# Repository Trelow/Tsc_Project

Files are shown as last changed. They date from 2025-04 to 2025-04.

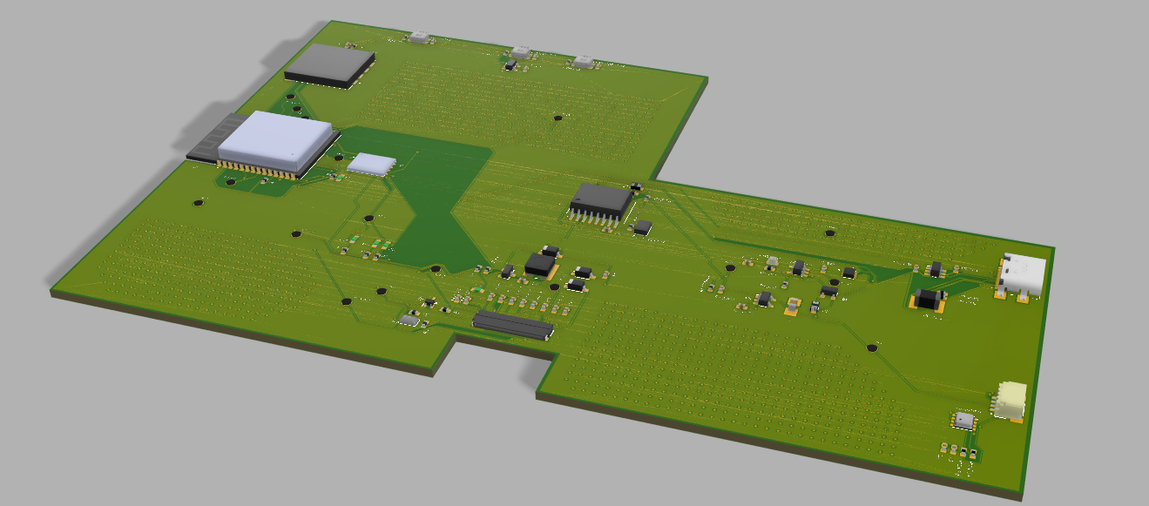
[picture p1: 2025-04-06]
Images/4.png

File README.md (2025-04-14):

# OpenBook Reader

```mermaid
graph TD
    
    USB["USB-C Connector(ESD Protection)"] -->|5V| CHG["Battery Charger (MCP73831)"]
    CHG -->|Charging| BATT["Li-Po Battery (2500mAh)"]
    BATT --> LDO["3.3V LDO Regulator (XC6220)"]

    LDO -->|3.3V| ESP["ESP32-C6-WROOM-1(MCU)"]

    ESP -- I2C --> RTC["Real Time Clock(DS3231)"]
    ESP -- I2C --> BME["Environmental Sensor(BME688)"]
    ESP -- I2C --> FUEL["Battery Fuel Gauge(MAX17048)"]
    ESP -- I2C --> QWIIC["Qwiic / Stemma QT"]

    ESP -- SPI --> FLASH["External NOR Flash(W25Q512)"]
    ESP -- SPI --> SD["MicroSD Card Slot"]
    ESP -- SPI --> EPD_HEADER["E-Paper Display Header"]

    EPD_HEADER --> EPD_DRIVER["EPD Driver Circuit"]
    EPD_DRIVER --> EPD_POW["EPD HV Power"]
    LDO --> EPD_HEADER

    ESP -- GPIO --> BUTTONS["3x Buttons:BOOT, CHANGE, RESET"]

    USB -- USB D+/D- --> ESP
```

## Tabel Componente Principale (BOM)

| Parts | Device | Check Prices | Datasheet |
|---|---|---|---|
|R1, R2 .. | ESP32_WROVER_EAGLE-LTSPICE_RR0402 |https://componentsearchengine.com/part-view/R0402%201%25%20100%20K%20 | https://componentsearchengine.com/part-view/R0402%201%25%20100%20K%20 |
| L1 | 744043680IND_4828-WE-TPC_WRE |  https://eu.mouser.com/ProductDetail/Wurth-Elektronik/744043680?qs=PGXP4M47uW6VkZq%252BkzjrHA%3D%3D | https://eu.mouser.com/ProductDetail/Wurth-Elektronik/744043680?qs=PGXP4M47uW6VkZq%252BkzjrHA%3D%3D |
| IC1 | BD5229G-TR |https://componentsearchengine.com/part-view/BD5229G-TR/ROHM%20Semiconductor | https://componentsearchengine.com/part-view/BD5229G-TR/ROHM%20Semiconductor |
| SENSOR2 | ESP32_WROVER_BME680_BME680 | https://www.snapeda.com/parts/BME680/Bosch/view-part/?welcome=home | https://www.snapeda.com/parts/BME680/Bosch/view-part/?welcome=home |
| SJ1 | SJ | https://grabcad.com/library/solder-jumpers-1 | https://grabcad.com/library/solder-jumpers-1 |
| BOOT_BUTTON, CHANGE_BUTTON, RESET_BUTTON | BUTTON_CUSYOMV1 | https://industry.panasonic.com/global/en/products/control/switch/light-touch/number/evqpuj02k | https://industry.panasonic.com/global/en/products/control/switch/light-touch/number/evqpuj02k |
| C1, C2 .. | CPH3225A | https://www.snapeda.com/parts/CPH3225A/Seiko+Instruments/view-part/?ref=eda | - |
| U3 | DS3231SN# | https://www.snapeda.com/parts/DS3231SN%23/Analog+Devices/view-part/?ref=eda | [Datasheet](https://www.analog.com/media/en/technical-documentation/data-sheets/ds3231.pdf) |
| U2 | ESP32-C6-WROOM-1-N8 | https://www.snapeda.com/parts/ESP32-C6-WROOM-1-N8/Espressif+Systems/view-part/?ref=eda | - |
| PFMF.050.1 | ESP32C6_VARISTORCN1812| https://www.mouser.co.uk/ProductDetail/EPCOS-TDK/B72520T0350K062?qs=dEfas%2FXlABIszF52uu7vrg%3D%3D | https://www.mouser.co.uk/ProductDetail/EPCOS-TDK/B72520T0350K062?qs=dEfas%2FXlABIszF52uu7vrg%3D%3D |
| D2 | ESP32_WROVER_AVX---SD0805S020S1R0 | https://eu.mouser.com/ProductDetail/KYOCERA-AVX/SD0805S020S1R0?qs=jCA%252BPfw4LHbpkAoSnwrdjw%3D%3D | http://datasheets.avx.com/schottky.pdf |
| MCP73831 | ESP32_WROVER_SPARKFUN-IC-POWER_MCP73831 |  https://eu.mouser.com/ProductDetail/Microchip-Technology/MCP73831T-2ACI-OT?qs=yUQqVecv4qvbBQBGbHx0Mw%3D%3Dcf |
| J1 | FH34SRJ-24S-0.5SH_99_ | https://componentsearchengine.com/part-view/XC6220A331MR-G/Torex | https://componentsearchengine.com/part-view/XC6220A331MR-G/Torex |
| U4 | MAX17048G+T10 | https://www.snapeda.com/parts/MAX17048G+T10/Analog+Devices/view-part/?ref=eda | - |
| D3, D4, D5 | MBR0530 | https://www.snapeda.com/parts/MBR0530/Onsemi/view-part/?ref=eda | - |
| D6, D8, D9, D10, D11, D12 | PGB1010603MR | https://www.snapeda.com/parts/PGB1010603MR/Littelfuse/view-part/?ref=eda | - |
| J3 | QWIIC_CONNECTORJS-1MM | - | - |
| J2 | SAMACSYS_PARTS_USB4110-GF-A |https://www.mouser.com/ProductDetail/GCT/USB4110-GF-A | https://gct.co/files/drawings/usb4110.pdf |
| D7 | ESP32_WROVER_AVX---SD0805S020S1R0 | - | [Datasheet](http://datasheets.avx.com/schottky.pdf) |
| BOOT_BUTTON | EVQPUJ02K | https://www.mouser.com/ProductDetail/Panasonic/EVQPUJ02K | [Datasheet](https://na.industrial.panasonic.com/file-download/21900) |
| Q3 | SI1308EDL-T1-GE3 | https://componentsearchengine.com/part-view/SI1308EDL-T1-GE3/Vishay | https://componentsearchengine.com/part-view/SI1308EDL-T1-GE3/Vishay |
| TP1, TP2, ..., TP17 | TPTP20R | - | - |
| D1 | USBLC6-2SC6Y |  https://www.snapeda.com/parts/USBLC6-2SC6Y/STMicroelectronics/view-part/?ref=eda | https://www.snapeda.com/parts/USBLC6-2SC6Y/STMicroelectronics/view-part/?ref=eda |
| U1 | W25Q512JVEIQ | https://www.snapeda.com/parts/W25Q512JVEIQ/Winbond+Electronics/view-part/?ref=eda | - |
| IC4 | XC6220A331MR-G | https://www.mouser.com/ProductDetail/Torex-Semiconductor/XC6220A331MR-G) | https://www.torexsemi.com/file/xc6220/XC6220.pdf |

## Descriere Detaliată a Funcționalității Hardware

### 1. Microcontroller – ESP32-C6
Dispozitivul folosește microcontroller-ul ESP32-C6-WROOM-1-N8, echipat cu un nucleu RISC-V pe 32 de biți, cu o frecvență maximă de 160 MHz.

- **Memorie:** 512 KB SRAM internă și flash extern de 8 MB (W25Q512JVEIQ).
- **Conectivitate:** Wi-Fi 6, Bluetooth 5 LE, interfață USB 2.0.
- **Periferice:** Suport SPI, I²C, UART și GPIO multipli.
- **Eficiență energetică:** Moduri sleep și deep sleep optimizate pentru utilizarea eficientă a bateriei.

### 2. Afișaj E-Paper
Afișaj E-Ink de 7.5” cu rezoluție de 800×480 pixeli

- **Interfață:** SPI 4-wire cu pini adiționali (CS, DC, RST, BUSY).
- **Consum:** Foarte redus în stare statică; crește doar temporar în timpul actualizării imaginii (aproximativ 15-25 mA).
- **Beneficii:** Imaginea este păstrată fără consum electric, ideal pentru dispozitive portabile tip e-reader.

### 3. Senzor Mediu – BME680
Senzor multifuncțional care măsoară temperatura, umiditatea, presiunea atmosferică și calitatea aerului (VOC/eCO₂).

- **Interfață:** I²C cu viteză de până la 400 kHz.
- **Consum:** Aproximativ 2.1µA în mod standby și câțiva mA la citiri active.
- **Avantaj principal:** Integrează multiple funcții de mediu într-un singur cip compact și eficient.

### 4. Management Energetic & Baterie
Sistemul energetic este bazat pe o baterie Li-Po de 3.7V și capacitate de 2500mAh, pentru autonomie extinsă.

- **Încărcare:** MCP73831, încărcare rapidă prin USB-C (maxim 1A).
- **Monitorizare:** MAX17048 comunică starea bateriei prin interfața I²C.
- **Regulator:** XC6220A331MR-G oferă tensiunea stabilă de 3.3V pentru componentele critice.

### 5. Interfață Utilizator – Butoane
Sunt incluse trei butoane tactile dedicate navigării, selecției și întoarcerii paginilor, fiecare conectat la GPIO cu debouncing hardware (rezistor și condensator) sau software.

### 6. Conector USB-C
- **Funcții principale:** Încărcarea acumulatorului, transferul de date (USB 2.0) și actualizarea firmware-ului. Utilizare de diode ESD (ex: USBLC6-2SC6Y) și rezistențe specifice pentru conformitate cu USB-C.

### 8. Slot MicroSD (112A-TAAR-R03)
- **Utilizare:** Stocare log-uri, cărți electronice și actualizări de firmware.
- **Interfață:** Compatibil cu SD (mod 1-bit sau 4-bit) sau SPI, configurabil în firmware.

### 8. Conector Qwiic (I²C)
Conector standardizat cu patru pini (VCC, GND, SDA, SCL) pentru extinderea rapidă a funcționalităților prin senzori sau module suplimentare.

### 9. RTC DS3231
- **Precizie:** Foarte ridicată.
- **Interfață:** Comunicare I²C integrată cu ceilalți senzori.

### 10. Memorie Flash Externă – W25Q512JVEIQ
- **Interfață:** Quad SPI pentru acces rapid la date.
- **Utilizare:** Stocarea aplicațiilor, imaginilor și fișierelor mari, inclusiv cărți electronice.

## Estimare Consum Energetic
- **Activ (Wi-Fi + refresh ecran):** Aproximativ 150 mA
- **Citire (ecran static):** Aproximativ 10 mA
- **Deep Sleep:** Sub 50 µA
- **Autonomie:** Aproximativ o săptămână, considerând un consum mediu de 10 mA (2500mAh ~250 ore utilizare).

## Estimare Consum de Energie
- **Activ (Wi-Fi + Refresh ecran)**: ~150mA  
- **Citire (ecran static)**: ~10mA  
- **Deep Sleep**: <50µA  
- **Autonomie estimată**: ~1 săptămână (la o utilizare medie de 10mA, o baterie de 2500mAh durează ~250 ore).

---

## Atribuirea Pinilor pe ESP32-C6

| Pin  | Funcție | Componentă | Descriere Utilizare |
|-----:|:---|:---|:---|
| GPIO0  | BOOT_BUTTON | Buton | Boot mode la pornire |
| GPIO1  | RESET_BUTTON | Buton | Reset manual |
| GPIO2  | CHANGE_BUTTON  | Buton | Navigare meniu |
| GPIO3  | EPD_CS | Display E-Paper | Chip Select (SPI) |
| GPIO4  | EPD_DC | Display E-Paper | Data/Command control |
| GPIO5  | EPD_RST | Display E-Paper | Reset ecran |
| GPIO6  | EPD_BUSY | Display E-Paper | Semnal stare refresh |
| GPIO7  | SPI_MOSI | Display, Flash, SD  | Master Out Slave In (SPI) |
| GPIO8  | SPI_MISO | Display, Flash, SD  | Master In Slave Out (SPI) |
| GPIO9  | SPI_SCK | Display, Flash, SD  | Clock SPI |
| GPIO10 | FLASH_CS | W25Q512JVEIQ | Chip Select pentru Flash |
| GPIO11 | SD_CS | Micro SD (opțional) | Chip Select card SD |
| GPIO12 | I2C_SDA | BME680, MAX17048, DS3231 | Linie date I2C |
| GPIO13 | I2C_SCL | BME680, MAX17048, DS3231 | Linie clock I2C |
| GPIO14 | CHG_LED | LED încărcare | Status încărcare |
| GPIO15 | UART_TX | Debugging | TX serial |
| GPIO16 | UART_RX | Debugging | RX serial |
| GPIO17 | USB_D+ | USB-C | Linie date USB + |
| GPIO18 | USB_D- | USB-C | Linie date USB – |

---

## Concluzii
Prin acest README, aveți la dispoziție elementele cheie ale construcției hardware pentru e-reader-ul **OpenBook**: modulul ESP32-C6, ecranul e-paper, senzorii, alimentarea și circuitele de încărcare. Fișierul CSV atașat oferă o listă detaliată a componentelor (BOM).

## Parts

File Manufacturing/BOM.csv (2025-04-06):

Qty | Value | Device | Package | Parts | Description | ARROW_PART_NUMBER | ARROW_PRICE-STOCK | AVAILABILITY | CENTROID_NOT_SPECIFIED | CHECK_PRICES | COPYRIGHT | DATASHEET | DESCRIPTION | DIGIKEY_DESCRIPTION | DIGIKEY_PART_NUMBER | HEIGHT | LEAD_FREE | MANUFACTURER_NAME | MANUFACTURER_PART_NUMBER | MF | MFR_NAME | MOUSER_PART_NUMBER | MOUSER_PRICE-STOCK | MOUSER_TESTING_PART_NUMBER | MOUSER_TESTING_PRICE-STOCK | MP | MPN | PACKAGE | POPULARITY | PREFIX | PRICE | PROD_ID | PURCHASE-URL | P_CHANNEL | ROHS | SNAPEDA_LINK | SPICEMODEL | SPICEPREFIX | TEMPERATURE_RANGE_HIGH | TEMPERATURE_RANGE_LOW | TP_SIGNAL_NAME | TYPE | VALUE | VALUE_TXT
1 |  | ADAFRUIT_LEDCHIP-LED0603 | ADAFRUIT_CHIP-LED0603 | CHG_LED | LED
1 |  | SJ | SJ | SJ1 | SMD solder JUMPER |  |  |  |  |  |  |  |  |  |  |  |  |  |  |  |  |  |  |  |  |  |  |  | 3
1 | 0.1uF/50V | ESP32_WROVER_EAGLE-LTSPICE_CC0402 | ESP32_WROVER_EAGLE-LTSPICE_C0402 | EPD_C5 | CAPACITOR, European symbol |  |  |  |  |  |  |  |  |  |  |  |  |  |  |  |  |  |  |  |  |  |  |  |  |  |  |  |  |  |  |  | NONE | C
1 | 0.47 | ESP32_WROVER_EAGLE-LTSPICE_RR0402 | ESP32_WROVER_EAGLE-LTSPICE_R0402 | R3 | RESISTOR, European symbol |  |  |  |  |  |  |  |  |  |  |  |  |  |  |  |  |  |  |  |  |  |  |  |  |  |  |  |  |  |  |  | NONE | R
1 | 100K | ESP32_WROVER_EAGLE-LTSPICE_RR0402 | ESP32_WROVER_EAGLE-LTSPICE_R0402 | R1_PWRUSB | RESISTOR, European symbol |  |  |  |  |  |  |  |  |  |  |  |  |  |  |  |  |  |  |  |  |  |  |  |  |  |  |  |  |  |  |  | NONE | R
8 | 100nF | ESP32_WROVER_EAGLE-LTSPICE_CC0402 | ESP32_WROVER_EAGLE-LTSPICE_C0402 | C1, C2, C4_USB, C6, C8, C9, C10, C_DELAY | CAPACITOR, European symbol |  |  |  |  |  |  |  |  |  |  |  |  |  |  |  |  |  |  |  |  |  |  |  |  |  |  |  |  |  |  |  | NONE | C
1 | 100uF | RCL_CPOL-EUCT3528 | RCL_CT3528 | C3 | POLARIZED CAPACITOR, European symbol |  |  |  |  |  |  |  |  |  |  |  |  |  |  |  |  |  |  |  |  |  |  |  | 0 |  |  |  |  |  |  |  |  | C |  |  |  | TANT
16 | 10K | ESP32_WROVER_EAGLE-LTSPICE_RR0402 | ESP32_WROVER_EAGLE-LTSPICE_R0402 | R1, R1_PINH, R1_PINH1, R2_PINH, R2_PINH1, R4, R5, R6, R7, R8, R9, R10, R_BOOT, R_CHANGE, R_CL1, R_RESET | RESISTOR, European symbol |  |  |  |  |  |  |  |  |  |  |  |  |  |  |  |  |  |  |  |  |  |  |  |  |  |  |  |  |  |  |  | NONE | R
1 | 10uF | ESP32_WROVER_EAGLE-LTSPICE_CC0402 | ESP32_WROVER_EAGLE-LTSPICE_C0402 | C7 | CAPACITOR, European symbol |  |  |  |  |  |  |  |  |  |  |  |  |  |  |  |  |  |  |  |  |  |  |  |  |  |  |  |  |  |  |  | NONE | C
1 | 112A-TAAR-R03_ATTEND | 112A-TAAR-R03_ATTEND | 112ATAARR03ATTEND | J4 | Micro SD Card Socket, Push-Push Type, Top Mount, SMT, H=1.83mm, 10u |  |  |  |  |  |  |  | Micro SD Card Socket | Push-Push Type | Top Mount | SMT | H=1.83mm | 10u |  |  | 1.9mm |  | ATTEND | 112A-TAAR-R03 ATTEND
1 | 15 | ESP32_WROVER_EAGLE-LTSPICE_RR0402 | ESP32_WROVER_EAGLE-LTSPICE_R0402 | R1_CAPACITOR | RESISTOR, European symbol |  |  |  |  |  |  |  |  |  |  |  |  |  |  |  |  |  |  |  |  |  |  |  |  |  |  |  |  |  |  |  | NONE | R
1 | 1uF | ESP32_WROVER_EAGLE-LTSPICE_CC0402 | ESP32_WROVER_EAGLE-LTSPICE_C0402 | C5 | CAPACITOR, European symbol |  |  |  |  |  |  |  |  |  |  |  |  |  |  |  |  |  |  |  |  |  |  |  |  |  |  |  |  |  |  |  | NONE | C
9 | 1uF/50V | ESP32_WROVER_EAGLE-LTSPICE_CC0402 | ESP32_WROVER_EAGLE-LTSPICE_C0402 | EPD_C1, EPD_C2, EPD_C6, EPD_C7, EPD_C8, EPD_C9, EPD_C10, EPD_C11, EPD_C12 | CAPACITOR, European symbol |  |  |  |  |  |  |  |  |  |  |  |  |  |  |  |  |  |  |  |  |  |  |  |  |  |  |  |  |  |  |  | NONE | C
1 | 2.2 | ESP32_WROVER_EAGLE-LTSPICE_RR0402 | ESP32_WROVER_EAGLE-LTSPICE_R0402 | R2 | RESISTOR, European symbol |  |  |  |  |  |  |  |  |  |  |  |  |  |  |  |  |  |  |  |  |  |  |  |  |  |  |  |  |  |  |  | NONE | R
1 | 200 | ESP32_WROVER_EAGLE-LTSPICE_RR0402 | ESP32_WROVER_EAGLE-LTSPICE_R0402 | R1_BAT | RESISTOR, European symbol |  |  |  |  |  |  |  |  |  |  |  |  |  |  |  |  |  |  |  |  |  |  |  |  |  |  |  |  |  |  |  | NONE | R
2 | 20V/4.2A/52m?/1.4W | ESP32_WROVER_SPARKFUN-DISCRETESEMI_MOSFET_PCH-DMG2305UX-7 | ESP32_WROVER_SPARKFUN-DISCRETESEMI_SOT23-3 | Q1, Q2 | P-channel MOSFETs |  |  |  |  |  |  |  |  |  |  |  |  |  |  |  |  |  |  |  |  |  |  |  |  |  |  | TRAN-14388 |  | DMG2305UX-7 |  |  |  |  |  |  |  |  | 20V/4.2A/52m?/1.4W
1 | 2K | ESP32_WROVER_EAGLE-LTSPICE_RR0402 | ESP32_WROVER_EAGLE-LTSPICE_R0402 | R2_BAT | RESISTOR, European symbol |  |  |  |  |  |  |  |  |  |  |  |  |  |  |  |  |  |  |  |  |  |  |  |  |  |  |  |  |  |  |  | NONE | R
5 | 4.7uF | ESP32_WROVER_EAGLE-LTSPICE_CC0402 | ESP32_WROVER_EAGLE-LTSPICE_C0402 | C1_BAT, C1_BAT1, C1_BAT2, C2_BAT, C5_USB | CAPACITOR, European symbol |  |  |  |  |  |  |  |  |  |  |  |  |  |  |  |  |  |  |  |  |  |  |  |  |  |  |  |  |  |  |  | NONE | C
1 | 4.7uF/25V | ESP32_WROVER_EAGLE-LTSPICE_CC0402 | ESP32_WROVER_EAGLE-LTSPICE_C0402 | C4 | CAPACITOR, European symbol |  |  |  |  |  |  |  |  |  |  |  |  |  |  |  |  |  |  |  |  |  |  |  |  |  |  |  |  |  |  |  | NONE | C
2 | 5k1 | ESP32_WROVER_EAGLE-LTSPICE_RR0402 | ESP32_WROVER_EAGLE-LTSPICE_R0402 | R2-USB, R2-USB1 | RESISTOR, European symbol |  |  |  |  |  |  |  |  |  |  |  |  |  |  |  |  |  |  |  |  |  |  |  |  |  |  |  |  |  |  |  | NONE | R
1 | 68uH | 744043680IND_4828-WE-TPC_WRE | IND_4828-WE-TPC_WRE | L1 |  |  |  |  |  |  | Copyright (C) 2024 Ultra Librarian. All rights reserved. |  |  |  |  |  |  |  | 744043680 |  | Wurth Electronics
1 | BD5229G-TR | BD5229G-TR | SOT95P280X125-5N | IC1 | Voltage Detector with Adjustable Delay Time: CMOS processes are utilized to develop high precision, low current consumption CMOS reset ICs that allow arbitrary setting of the delay time. The extensive lineup includes both Nch Open Drain and CMOS output types in a wide range of detection voltages (from 2.3V to 6.0V, in 0.1V steps), enabling selection of the ideal solution based on customer requirements. In addition, the entire series is of course both lead-free and RoHS-compliant. |  |  |  |  |  |  |  | Voltage Detector with Adjustable Delay Time: CMOS processes are utilized to develop high precision | low current consumption CMOS reset ICs that allow arbitrary setting of the delay time. The extensive lineup includes both Nch Open Drain and CMOS output types in a wide range of detection voltages (from 2.3V to 6.0V | in 0.1V steps) | enabling selection of the ideal solution based on customer requirements. In addition | the entire series is of course both lead-free and RoHS-compliant. |  |  | 1.25mm |  | ROHM Semiconductor | BD5229G-TR |  |  | 755-BD5229G-TR | https://www.mouser.co.uk/ProductDetail/ROHM-Semiconductor/BD5229G-TR?qs=4kLU8WoGk0vvnhrrYwdszw%3D%3D
1 | BME688 | ESP32_WROVER_BME680_BME680 | ESP32_WROVER_BME680_PSON80P300X300X100-8N | SENSOR2 | Integrated Environmental Unit |  |  | Unavailable |  |  |  |  | Integrated Environmental Unit |  |  |  |  |  |  | Bosch Sensortec |  |  |  |  |  | BME680 |  | LGA-8 Bosch Tools |  |  | None
3 | BUTTON_CUSYOMV1 | BUTTON_CUSYOMV1 | MYBUTTON | BOOT_BUTTON, CHANGE_BUTTON, RESET_BUTTON
1 | CPH3225A | CPH3225A | CAPCP3225X100N | C10_SUPERCAP | Cap 0.011F 3.3V 1210 Flat Check availability |  |  | Not in stock |  | https://www.snapeda.com/parts/CPH3225A/Seiko+Instruments/view-part/?ref=eda |  |  | 11 mF (EDLC) Supercapacitor 3.3 V 1210 (3225 Metric) - - |  |  |  |  |  |  | Seiko Instruments |  |  |  |  |  | CPH3225A |  | 1210 Seiko |  |  | None |  | https://www.snapeda.com/api/url_track_click_mouser/?unipart_id=562593&manufacturer=Seiko Instruments&part_name=CPH3225A&search_term=None |  |  | https://www.snapeda.com/parts/CPH3225A/Seiko+Instruments/view-part/?ref=snap
1 | DS3231SN# | DS3231SN# | SOIC127P1032X265-16N | U3 | Real Time Clock Serial 16-Pin SOIC W T/R Check availability |  |  | In Stock |  | https://www.snapeda.com/parts/DS3231SN%23/Analog+Devices/view-part/?ref=eda |  |  | Extremely Accurate I?C-Integrated RTC/TCXO/Crystal |  |  |  |  |  |  | Analog Devices |  |  |  |  |  | DS3231SN# |  | SOIC-16 Maxim |  |  | None |  | https://www.snapeda.com/api/url_track_click_mouser/?unipart_id=99048&manufacturer=Analog Devices&part_name=DS3231SN#&search_term=None |  |  | https://www.snapeda.com/parts/DS3231SN%23/Analog+Devices/view-part/?ref=snap
1 | ESP32-C6-WROOM-1-N8 | ESP32-C6-WROOM-1-N8 | XCVR_ESP32-C6-WROOM-1-N8 | U2 | Check availability |  |  | In Stock |  | https://www.snapeda.com/parts/ESP32-C6-WROOM-1-N8/Espressif+Systems/view-part/?ref=eda |  |  | Multiprotocol Modules ESP32-C6 module | Wi-Fi 6 in 2.4 GHz band | Bluetooth 5 | Zigbee 3.0 and Thread. ESP34-WROOM Compatible - ENGINEERING SAMPLE |  |  |  |  |  |  | Espressif Systems |  |  |  |  |  | ESP32-C6-WROOM-1-N8 |  | None |  |  | None |  |  |  |  | https://www.snapeda.com/parts/ESP32-C6-WROOM-1-N8/Espressif+Systems/view-part/?ref=snap
1 | ESP32C6_VARISTORCN1812 | ESP32C6_VARISTORCN1812 | ESP32C6_VARISTOR_CT/CN1812 | PFMF.050.1 | VARISTOR |  |  |  |  |  |  |  |  |  |  |  |  |  |  |  |  |  |  |  |  |  |  |  | 0
1 | ESP32_WROVER_AVX---SD0805S020S1R0_AVX_SD0805S020S1R0_0_0AVX_SD0805S020S1R0_0_0 | ESP32_WROVER_AVX---SD0805S020S1R0_AVX_SD0805S020S1R0_0_0AVX_SD0805S020S1R0_0_0 | ESP32_WROVER_AVX---SD0805S020S1R0_AVX_SD0805S020S1R0_0 | D2 | Schottky Barrier Rectifier Diode |  |  |  | No |  |  | http://datasheets.avx.com/schottky.pdf |  | DIODE SCHOTTKY 20V 1A 0805 | 478-7800-1-ND |  | yes |  |  | AVX |  | 581-SD0805S020S1R0 |  |  |  |  |  | 0805 (2012 metric) |  | D |  |  |  |  | yes |  |  |  | +125°C | -55°C |  |  |  | SD0805S020S1R0
1 | ESP32_WROVER_SPARKFUN-IC-POWER_MCP73831 | ESP32_WROVER_SPARKFUN-IC-POWER_MCP73831 | ESP32_WROVER_SPARKFUN-IC-POWER_SOT23-5 | MCP73831 | MCP73831T Li-Ion, Li-Pol Controller |  |  |  |  |  |  |  |  |  |  |  |  |  |  |  |  |  |  |  |  |  |  |  |  |  |  | IC-09995
1 | FH34SRJ-24S-0.5SH_99_ | FH34SRJ-24S-0.5SH_99_ | FH34SRJ24S05SH99 | J1 | (0.50mm) Surface Mount, Right Angle |  |  |  |  |  |  |  | 24 Position FFC | FPC Connector Contacts | (0.50mm) Surface Mount | Right Angle |  |  | 1.1mm |  | Hirose | FH34SRJ-24S-0.5SH(99) |  |  | 798-FH34SRJ24S05SH99 | https://www.mouser.co.uk/ProductDetail/Hirose-Connector/FH34SRJ-24S-0.5SH99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
1 | MAX17048G+T10 | MAX17048G+T10 | SON50P200X200X80-9N | U4 | Check availability |  |  | In Stock |  | https://www.snapeda.com/parts/MAX17048G+T10/Analog+Devices/view-part/?ref=eda |  |  | 3µA 1-Cell/2-Cell Fuel Gauge with ModelGauge |  |  |  |  |  |  | Analog Devices |  |  |  |  |  | MAX17048G+T10 |  | TDFN-8 Maxim |  |  | None |  | https://www.snapeda.com/api/url_track_click_mouser/?unipart_id=329239&manufacturer=Analog Devices&part_name=MAX17048G+T10&search_term=None |  |  | https://www.snapeda.com/parts/MAX17048G+T10/Analog+Devices/view-part/?ref=snap
3 | MBR0530 | MBR0530 | SOD3716X135N | D3, D4, D5 | ON SEMICONDUCTOR - MBR0530 - DIODE, SCHOTTKY, 0.5A, 30V, SOD-123 |  |  | In Stock |  | https://www.snapeda.com/parts/MBR0530/Onsemi/view-part/?ref=eda |  |  | Diode Schottky 30 V 500mA Surface Mount SOD-123 |  |  |  |  |  |  | ON Semiconductor |  |  |  |  |  | MBR0530 |  | SOD-123-2 ON Semiconductor |  |  | None |  | https://www.snapeda.com/api/url_track_click_mouser/?unipart_id=179458&manufacturer=ON Semiconductor&part_name=MBR0530&search_term=None |  |  | https://www.snapeda.com/parts/MBR0530/Onsemi/view-part/?ref=snap
6 | PGB1010603MR | PGB1010603MR | DIOC1608X36N | D6, D8, D9, D10, D11, D12 | Check availability |  |  | In Stock |  | https://www.snapeda.com/parts/PGB1010603MR/Littelfuse/view-part/?ref=eda |  |  | 150V (Typ) Clamp - Ipp Tvs Diode Surface Mount 0603 (1608 Metric) |  |  |  |  |  |  | Littelfuse Inc. |  |  |  |  |  | PGB1010603MR |  | 0603 Littelfuse Inc. |  |  | None |  | https://www.snapeda.com/api/url_track_click_mouser/?unipart_id=5659453&manufacturer=Littelfuse Inc.&part_name=PGB1010603MR&search_term=None |  |  | https://www.snapeda.com/parts/PGB1010603MR/Littelfuse/view-part/?ref=snap
1 | QWIIC_RIGHT_ANGLE | QWIIC_CONNECTORJS-1MM | JST04_1MM_RA | J3 | SparkFun I2C Standard Qwiic Connector |  |  |  |  |  |  |  |  |  |  |  |  |  |  |  |  |  |  |  |  |  |  |  |  |  |  | CONN-13694 |  |  |  |  |  |  |  |  |  |  | QWIIC_RIGHT_ANGLE
1 | SAMACSYS_PARTS_USB4110-GF-A | SAMACSYS_PARTS_USB4110-GF-A | SAMACSYS_PARTS_USB4110GFA | J2 | CONN USB 2.0 TYPE-C R/A SMT |  |  |  |  |  |  |  | CONN USB 2.0 TYPE-C R/A SMT |  |  | 3.26mm |  | GCT (GLOBAL CONNECTOR TECHNOLOGY) | USB4110-GF-A |  |  | 640-USB4110-GF-A | https://www.mouser.co.uk/ProductDetail/GCT/USB4110-GF-A?qs=KUoIvG%2F9IlYiZvIXQjyJeA%3D%3D
1 | SD0805S020S1R0 | ESP32_WROVER_AVX---SD0805S020S1R0_AVX_SD0805S020S1R0_0_0AVX_SD0805S020S1R0_0_0 | ESP32_WROVER_AVX---SD0805S020S1R0_AVX_SD0805S020S1R0_0 | D7 | Schottky Barrier Rectifier Diode |  |  |  | No |  |  | http://datasheets.avx.com/schottky.pdf |  | DIODE SCHOTTKY 20V 1A 0805 | 478-7800-1-ND |  | yes |  |  | AVX |  | 581-SD0805S020S1R0 |  |  |  |  |  | 0805 (2012 metric) |  | D |  |  |  |  | yes |  |  |  | +125°C | -55°C |  |  |  | SD0805S020S1R0
1 | SI1308EDL-T1-GE3 | SI1308EDL-T1-GE3 | SOT65P210X110-3N | Q3 | MOSFET N-Ch 30V 1.5A TrenchFET SC70 Vishay Si1308EDL-T1-GE3 N-channel MOSFET Transistor, 1.5 A, 30 V, 3-Pin SC-70 |  |  | In Stock |  | https://www.snapeda.com/parts/SI1308EDL-T1-GE3/Vishay+Siliconix/view-part/?ref=eda |  |  | Si1308EDL-T1-GE3 N-channel MOSFET Transistor | 1.5 A | 30 V | 3-Pin SC-70 | Siliconix / Vishay SI1308EDL-T1-GE3 |  |  |  |  |  |  | Vishay Siliconix |  |  |  |  |  | SI1308EDL-T1-GE3 |  | SOT-323 Vishay Semiconductor |  |  | None |  | https://www.snapeda.com/api/url_track_click_mouser/?unipart_id=274603&manufacturer=Vishay Siliconix&part_name=SI1308EDL-T1-GE3&search_term=None |  |  | https://www.snapeda.com/parts/SI1308EDL-T1-GE3/Vishay+Siliconix/view-part/?ref=snap
17 | TPTP20R | TPTP20R | TP20R | TP1, TP2, TP3, TP4, TP5, TP6, TP7, TP8, TP9, TP10, TP11, TP12, TP13, TP14, TP15, TP16, TP17 | Test pad |  |  |  |  |  |  |  |  |  |  |  |  |  |  |  |  |  |  |  |  |  |  |  | 2
1 | USBLC6-2SC6Y | USBLC6-2SC6Y | SOT95P280X145-6N | D1 | Low Cap. ESD Protection Auto SOT-23-6 STMicroelectronics USBLC6-2SC6Y, Dual Uni-Directional TVS Diode Array, 6-Pin SOT-23 |  |  | In Stock |  | https://www.snapeda.com/parts/USBLC6-2SC6Y/STMicroelectronics/view-part/?ref=eda |  |  | 17V Clamp 5A (8/20µs) Ipp Tvs Diode Surface Mount SOT-23-6 |  |  |  |  |  |  | STMicroelectronics |  |  |  |  |  | USBLC6-2SC6Y |  | SOT-23-6 STMicroelectronics |  |  | None |  |  |  |  | https://www.snapeda.com/parts/USBLC6-2SC6Y/STMicroelectronics/view-part/?ref=snap
1 | W25Q512JVEIQ | W25Q512JVEIQ | SON127P600X800X80-9N | U1 | Check availability |  |  | In Stock |  | https://www.snapeda.com/parts/W25Q512JVEIQ/Winbond+Electronics/view-part/?ref=eda |  |  | FLASH - NOR Memory IC 512Mb (64M x 8) SPI - Quad I/O 133 MHz 8-WSON (8x6) |  |  |  |  |  |  | Winbond Electronics |  |  |  |  |  | W25Q512JVEIQ |  | Package |  |  | None |  |  |  |  | https://www.snapeda.com/parts/W25Q512JVEIQ/Winbond+Electronics/view-part/?ref=snap
1 | XC6220A331MR-G | XC6220A331MR-G | SOT95P280X120-5N | IC4 | LDO Voltage Regulators |  |  |  |  |  |  |  | LDO Voltage Regulators |  |  | 1.2mm |  | Torex | XC6220A331MR-G |  |  | 865-XC6220A331MR-G | https://www.mouser.co.uk/ProductDetail/Torex-Semiconductor/XC6220A331MR-G?qs=AsjdqWjXhJ8ZSWznL1J0gg%3D%3D

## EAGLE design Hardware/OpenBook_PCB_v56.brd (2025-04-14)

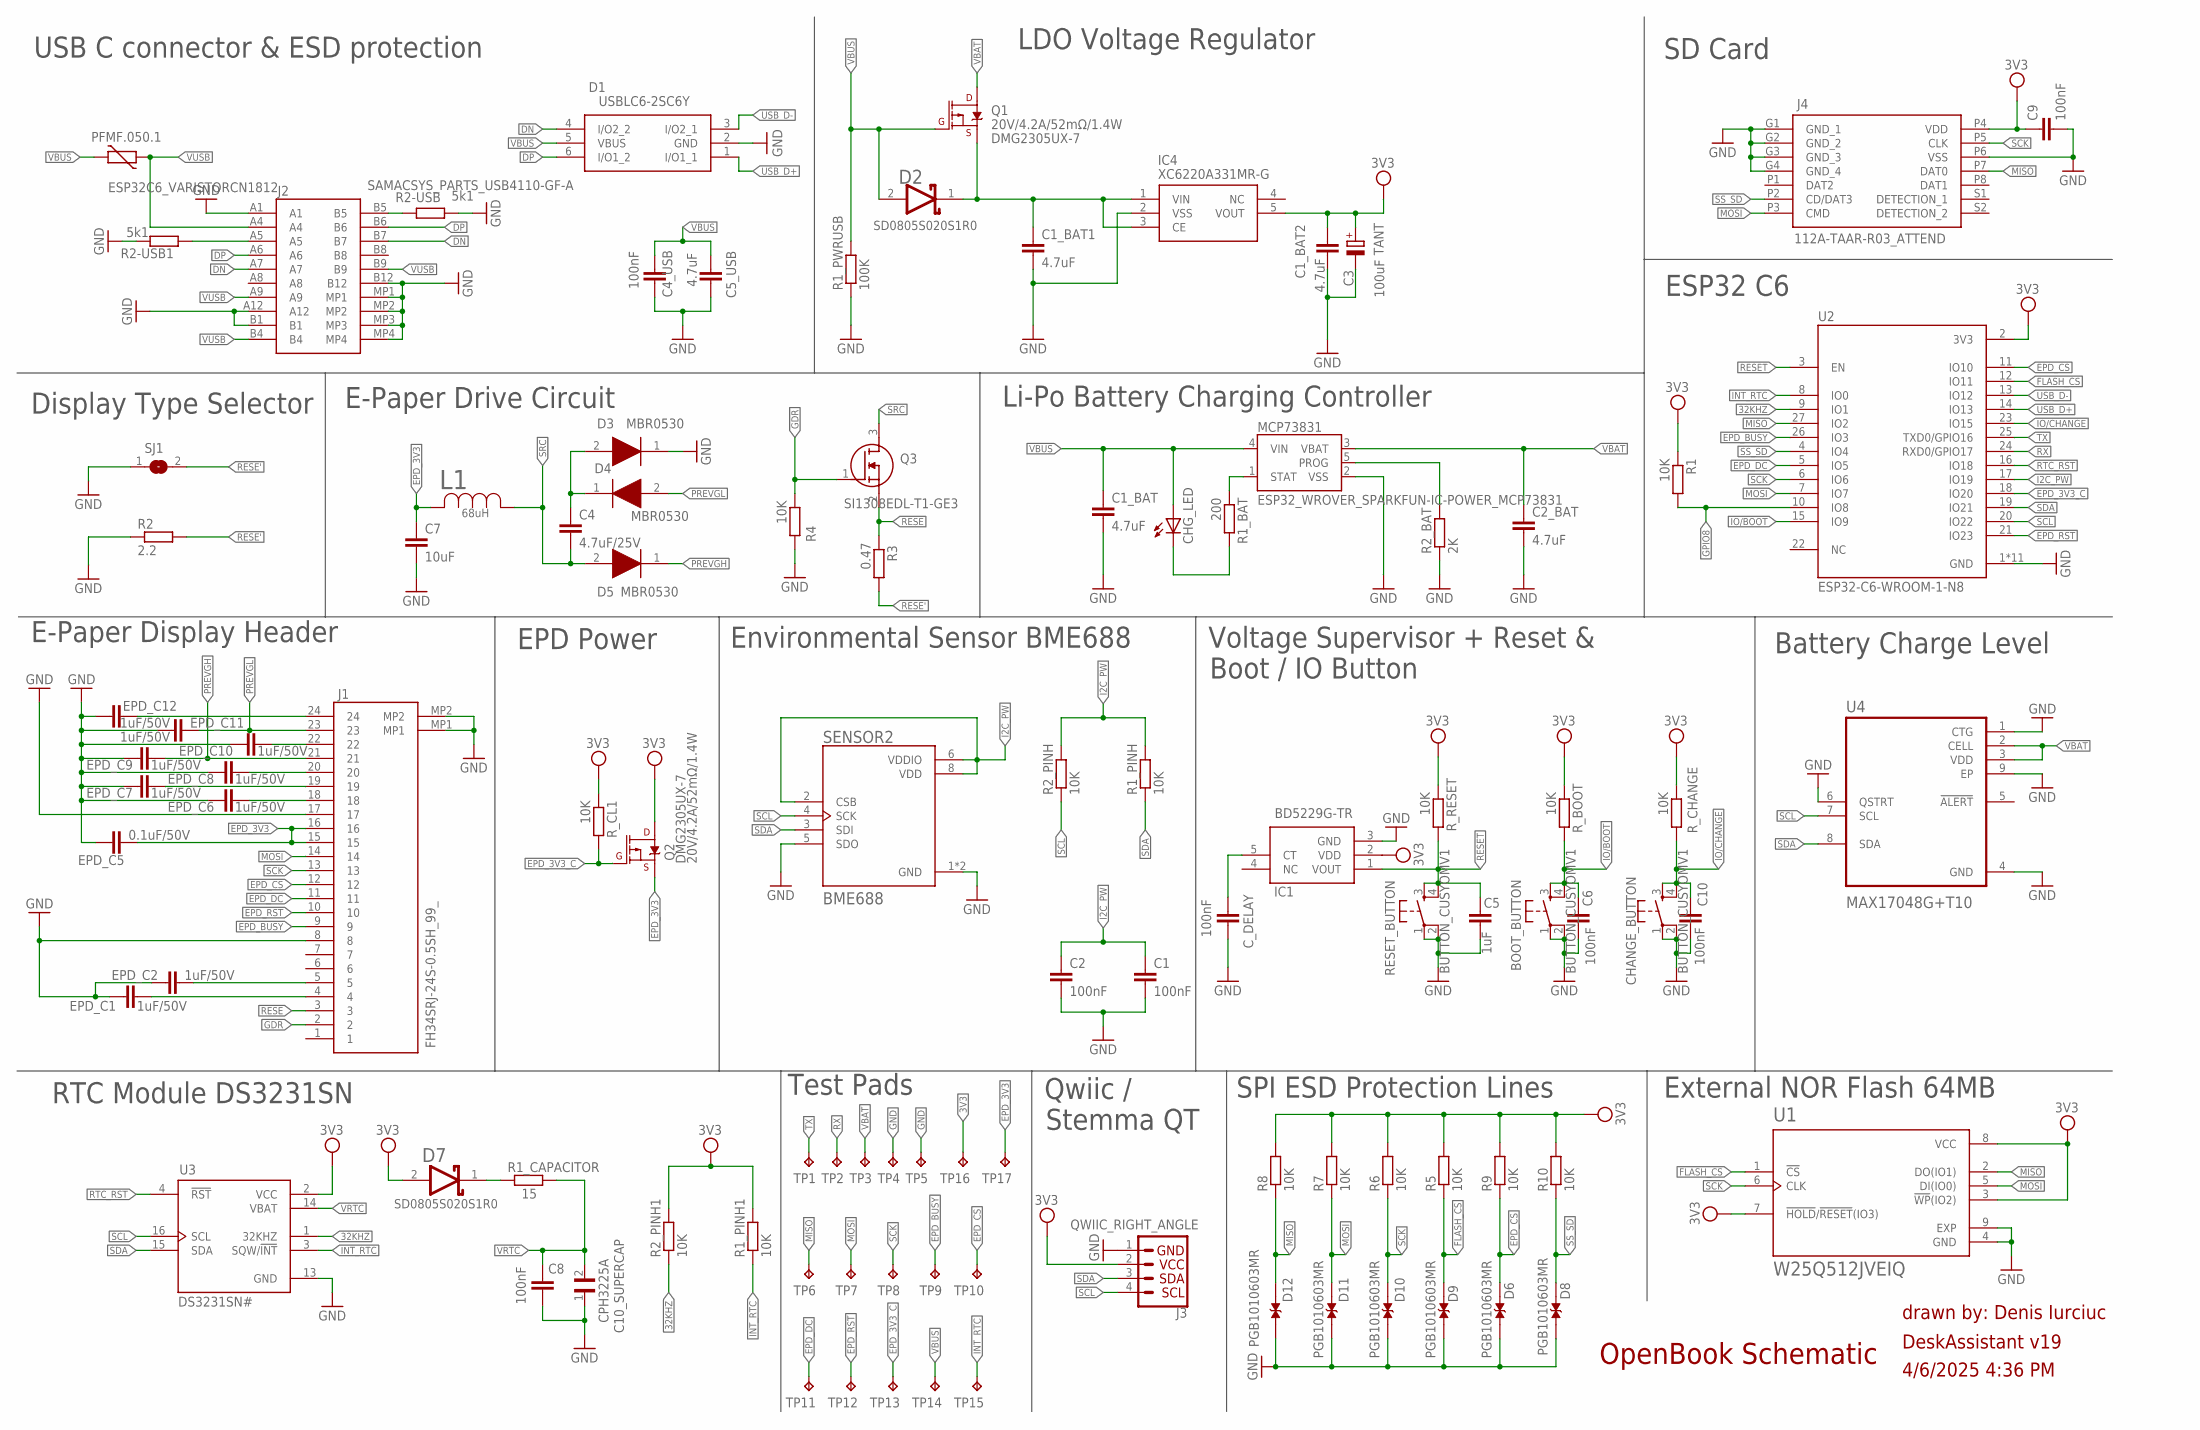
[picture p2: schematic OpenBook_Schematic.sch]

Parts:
BOOT_BUTTON: BUTTON_CUSYOMV1; MYBUTTON
C1, C2, C4_USB, C6, C8, C9, C10: 100nF; ESP32_WROVER_EAGLE-LTSPICE_C0402
C1_BAT, C1_BAT1, C1_BAT2, C2_BAT, C5_USB: 4.7uF; ESP32_WROVER_EAGLE-LTSPICE_C0402
C3: 100uF; RCL_CT3528
C4: 4.7uF/25V; ESP32_WROVER_EAGLE-LTSPICE_C0402
C5: 1uF; ESP32_WROVER_EAGLE-LTSPICE_C0402
C7: 10uF; ESP32_WROVER_EAGLE-LTSPICE_C0402
C10_SUPERCAP: CPH3225A; CAPCP3225X100N
CHANGE_BUTTON: BUTTON_CUSYOMV1; MYBUTTON
CHG_LED: ADAFRUIT_LEDCHIP-LED0603; ADAFRUIT_CHIP-LED0603
C_DELAY: 100nF; ESP32_WROVER_EAGLE-LTSPICE_C0402
D1: USBLC6-2SC6Y; SOT95P280X145-6N
D2: ESP32_WROVER_AVX---SD0805S020S1R0_AVX_SD0805S020S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; ESP32_WROVER_AVX---SD0805S020S1R0_AVX_SD0805S020S1R0_0
D3, D4, D5: MBR0530; SOD3716X135N
D6, D8, D9, D10, D11, D12: PGB1010603MR; DIOC1608X36N
D7: SD0805S020S1R0; ESP32_WROVER_AVX---SD0805S020S1R0_AVX_SD0805S020S1R0_0
EPD_C1, EPD_C2, EPD_C6, EPD_C7, EPD_C8, EPD_C9, EPD_C10, EPD_C11, EPD_C12: 1uF/50V; ESP32_WROVER_EAGLE-LTSPICE_C0402
EPD_C5: 0.1uF/50V; ESP32_WROVER_EAGLE-LTSPICE_C0402
IC1: BD5229G-TR; SOT95P280X125-5N
IC4: XC6220A331MR-G; SOT95P280X120-5N
J1: FH34SRJ-24S-0.5SH_99_; FH34SRJ24S05SH99
J2: SAMACSYS_PARTS_USB4110-GF-A; SAMACSYS_PARTS_USB4110GFA
J3: QWIIC_RIGHT_ANGLE; JST04_1MM_RA
J4: 112A-TAAR-R03_ATTEND; 112ATAARR03ATTEND
L1: 68uH; IND_4828-WE-TPC_WRE
MCP73831: ESP32_WROVER_SPARKFUN-IC-POWER_MCP73831; ESP32_WROVER_SPARKFUN-IC-POWER_SOT23-5
PFMF.050.1: ESP32C6_VARISTORCN1812; ESP32C6_VARISTOR_CT/CN1812
Q1, Q2: 20V/4.2A/52mΩ/1.4W; ESP32_WROVER_SPARKFUN-DISCRETESEMI_SOT23-3
Q3: SI1308EDL-T1-GE3; SOT65P210X110-3N
R1, R1_PINH, R1_PINH1, R2_PINH, R2_PINH1, R4, R5, R6, R7, R8, R9, R10: 10K; ESP32_WROVER_EAGLE-LTSPICE_R0402
R1_BAT: 200; ESP32_WROVER_EAGLE-LTSPICE_R0402
R1_CAPACITOR: 15; ESP32_WROVER_EAGLE-LTSPICE_R0402
R1_PWRUSB: 100K; ESP32_WROVER_EAGLE-LTSPICE_R0402
R2: 2.2; ESP32_WROVER_EAGLE-LTSPICE_R0402
R2-USB, R2-USB1: 5k1; ESP32_WROVER_EAGLE-LTSPICE_R0402
R2_BAT: 2K; ESP32_WROVER_EAGLE-LTSPICE_R0402
R3: 0.47; ESP32_WROVER_EAGLE-LTSPICE_R0402
RESET_BUTTON: BUTTON_CUSYOMV1; MYBUTTON
R_BOOT: 10K; ESP32_WROVER_EAGLE-LTSPICE_R0402
R_CHANGE: 10K; ESP32_WROVER_EAGLE-LTSPICE_R0402
R_CL1: 10K; ESP32_WROVER_EAGLE-LTSPICE_R0402
R_RESET: 10K; ESP32_WROVER_EAGLE-LTSPICE_R0402
SENSOR2: BME688; ESP32_WROVER_BME680_PSON80P300X300X100-8N
SJ1: SJ
TP1, TP2, TP3, TP4, TP5, TP6, TP7, TP8, TP9, TP10, TP11, TP12, TP13, TP14, TP15, TP16, TP17: TPTP20R; TP20R
U1: W25Q512JVEIQ; SON127P600X800X80-9N
U2: ESP32-C6-WROOM-1-N8; XCVR_ESP32-C6-WROOM-1-N8
U3: DS3231SN#; SOIC127P1032X265-16N
U4: MAX17048G+T10; SON50P200X200X80-9N

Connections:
3V3: C1_BAT2.1, C3.+, C9.1, D7.2 (ANODE), IC1.2 (VDD), IC4.5 (VOUT), J3.2, J4.P4 (VDD), Q2.3 (D), R1.1, R1_PINH1.2, R2_PINH1.2, R5.2, R6.2, R7.2, R8.2, R9.2, R10.2, R_BOOT.1, R_CHANGE.1, R_CL1.1, R_RESET.1, TP16.TP, U1.3 (!WP!(IO2)), U1.7 (!HOLD!/!RESET!(IO3)), U1.8 (VCC), U2.2 (3V3), U3.2 (VCC)
32KHZ: R2_PINH1.1, U2.9 (IO1), U3.1 (32KHZ)
DN: D1.4 (I/O2_2), J2.A7, J2.B7
DP: D1.6 (I/O1_2), J2.A6, J2.B6
EPD_3V3: C7.1, EPD_C5.1, J1.15, J1.16, L1.2, Q2.2 (S), TP17.TP
EPD_3V3_C: Q2.1 (G), R_CL1.2, TP13.TP, U2.18 (IO20)
EPD_BUSY: J1.9, TP9.TP, U2.26 (IO3)
EPD_CS: D6.2, J1.12, R9.1, TP10.TP, U2.11 (IO10)
EPD_DC: J1.11, TP11.TP, U2.5 (IO5)
EPD_RST: J1.10, TP12.TP, U2.21 (IO23)
FLASH_CS: D9.2, R5.1, U1.1 (!CS), U2.12 (IO11)
GDR: J1.2, Q3.1 (G), R4.1
GND: BOOT_BUTTON.1, BOOT_BUTTON.2, C1.2, C1_BAT.2, C1_BAT1.2, C1_BAT2.2, C2.2, C2_BAT.2, C3.-, C4_USB.2, C5.2, C5_USB.2, C6.2, C7.2, C8.2, C9.2, C10.2, C10_SUPERCAP.1, CHANGE_BUTTON.1, CHANGE_BUTTON.2, C_DELAY.2, D1.2 (GND), D3.1 (K), D6.1, D8.1, D9.1, D10.1, D11.1, D12.1, EPD_C1.2, EPD_C2.2, EPD_C5.2, EPD_C6.2, EPD_C7.2, EPD_C8.2, EPD_C9.2, EPD_C10.2, EPD_C11.2, EPD_C12.2, IC1.3 (GND), IC4.2 (VSS), J1.8, J1.17, J1.MP1, J1.MP2, J2.A1, J2.A12, J2.B1, J2.B12, J2.MP1, J2.MP2, J2.MP3, J2.MP4, J3.1, J4.G1 (GND_1), J4.G2 (GND_2), J4.G3 (GND_3), J4.G4 (GND_4), J4.P6 (VSS), MCP73831.2 (VSS), R1_PWRUSB.1, R2.1, R2-USB.2, R2-USB1.1, R2_BAT.1, R4.2, RESET_BUTTON.1, RESET_BUTTON.2, SENSOR2.1 (GND), SENSOR2.5 (SDO), SENSOR2.7 (GND), SJ1.1, TP4.TP, TP5.TP, U1.4 (GND), U1.9 (EXP), U2.1 (GND), U2.28 (GND), U2.29_1 (GND), U2.29_2 (GND), U2.29_3 (GND), U2.29_4 (GND), U2.29_5 (GND), U2.29_6 (GND), U2.29_7 (GND), U2.29_8 (GND), U2.29_9 (GND), U3.13 (GND), U4.1 (CTG), U4.4 (GND), U4.6 (QSTRT), U4.9 (EP)
GPIO8: R1.2, U2.10 (IO8)
I2C_PW: C1.1, C2.1, R1_PINH.2, R2_PINH.2, SENSOR2.2 (CSB), SENSOR2.6 (VDDIO), SENSOR2.8 (VDD), U2.17 (IO19)
INT_RTC: R1_PINH1.1, TP15.TP, U2.8 (IO0), U3.3 (SQW/!INT)
IO/BOOT: BOOT_BUTTON.3, BOOT_BUTTON.4, C6.1, R_BOOT.2, U2.15 (IO9)
IO/CHANGE: C10.1, CHANGE_BUTTON.3, CHANGE_BUTTON.4, R_CHANGE.2, U2.23 (IO15)
MISO: D12.2, J4.P7 (DAT0), R8.1, TP6.TP, U1.2 (DO(IO1)), U2.27 (IO2)
MOSI: D11.2, J1.14, J4.P3 (CMD), R7.1, TP7.TP, U1.5 (DI(IO0)), U2.7 (IO7)
unnamed: J2.A5, R2-USB1.2
unnamed: J2.B5, R2-USB.1
unnamed: C1_BAT1.1, D2.1 (CATHODE), IC4.1 (VIN), IC4.3 (CE), Q1.2 (S)
unnamed: EPD_C12.1, J1.24
unnamed: CHG_LED.C, R1_BAT.2
unnamed: MCP73831.1 (STAT), R1_BAT.1
unnamed: MCP73831.5 (PROG), R2_BAT.2
unnamed: C4.1, D3.2 (A), D4.1 (K)
unnamed: EPD_C10.1, J1.22
unnamed: EPD_C8.1, J1.20
unnamed: EPD_C7.1, J1.19
unnamed: EPD_C6.1, J1.18
unnamed: C_DELAY.1, IC1.5 (CT)
unnamed: D7.1 (CATHODE), R1_CAPACITOR.1
unnamed: EPD_C2.1, J1.5
unnamed: EPD_C1.1, J1.4
PREVGH: D5.1 (K), EPD_C9.1, J1.21
PREVGL: D4.2 (A), EPD_C11.1, J1.23
RESE: J1.3, Q3.2 (S), R3.1
RESE': R2.2, R3.2, SJ1.2
RESET: C5.1, IC1.1 (VOUT), RESET_BUTTON.3, RESET_BUTTON.4, R_RESET.2, U2.3 (EN)
RTC_RST: U2.16 (IO18), U3.4 (!RST)
RX: TP2.TP, U2.24 (RXD0/GPIO17)
SCK: D10.2, J1.13, J4.P5 (CLK), R6.1, TP8.TP, U1.6 (CLK), U2.6 (IO6)
SCL: J3.4, R2_PINH.1, SENSOR2.4 (SCK), U2.20 (IO22), U3.16 (SCL), U4.7 (SCL)
SDA: J3.3, R1_PINH.1, SENSOR2.3 (SDI), U2.19 (IO21), U3.15 (SDA), U4.8 (SDA)
SRC: C4.2, D5.2 (A), L1.1, Q3.3 (D)
SS_SD: D8.2, J4.P2 (CD/DAT3), R10.1, U2.4 (IO4)
TX: TP1.TP, U2.25 (TXD0/GPIO16)
USB_D+: D1.1 (I/O1_1), U2.14 (IO13)
USB_D-: D1.3 (I/O2_1), U2.13 (IO12)
VBAT: C2_BAT.1, MCP73831.3 (VBAT), Q1.3 (D), TP3.TP, U4.2 (CELL), U4.3 (VDD)
VBUS: C1_BAT.1, C4_USB.1, C5_USB.1, CHG_LED.A, D1.5 (VBUS), D2.2 (ANODE), MCP73831.4 (VIN), PFMF.050.1.2, Q1.1 (G), R1_PWRUSB.2, TP14.TP
VRTC: C8.1, C10_SUPERCAP.2, R1_CAPACITOR.2, U3.14 (VBAT)
VUSB: J2.A4, J2.A9, J2.B4, J2.B9, PFMF.050.1.1

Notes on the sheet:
USB C connector & ESD protection
LDO Voltage Regulator
Display Type Selector
E-Paper Drive Circuit
Li-Po Battery Charging Controller
E-Paper Display Header
EPD Power
Environmental Sensor BME688
Voltage Supervisor + Reset &
Boot / IO Button
RTC Module DS3231SN
Test Pads
Qwiic /
Stemma QT
SPI ESD Protection Lines
SD Card
ESP32 C6
Battery Charge Level
External NOR Flash 64MB
OpenBook Schematic
drawn by: Denis Iurciuc
DeskAssistant v19
4/6/2025 4:36 PM

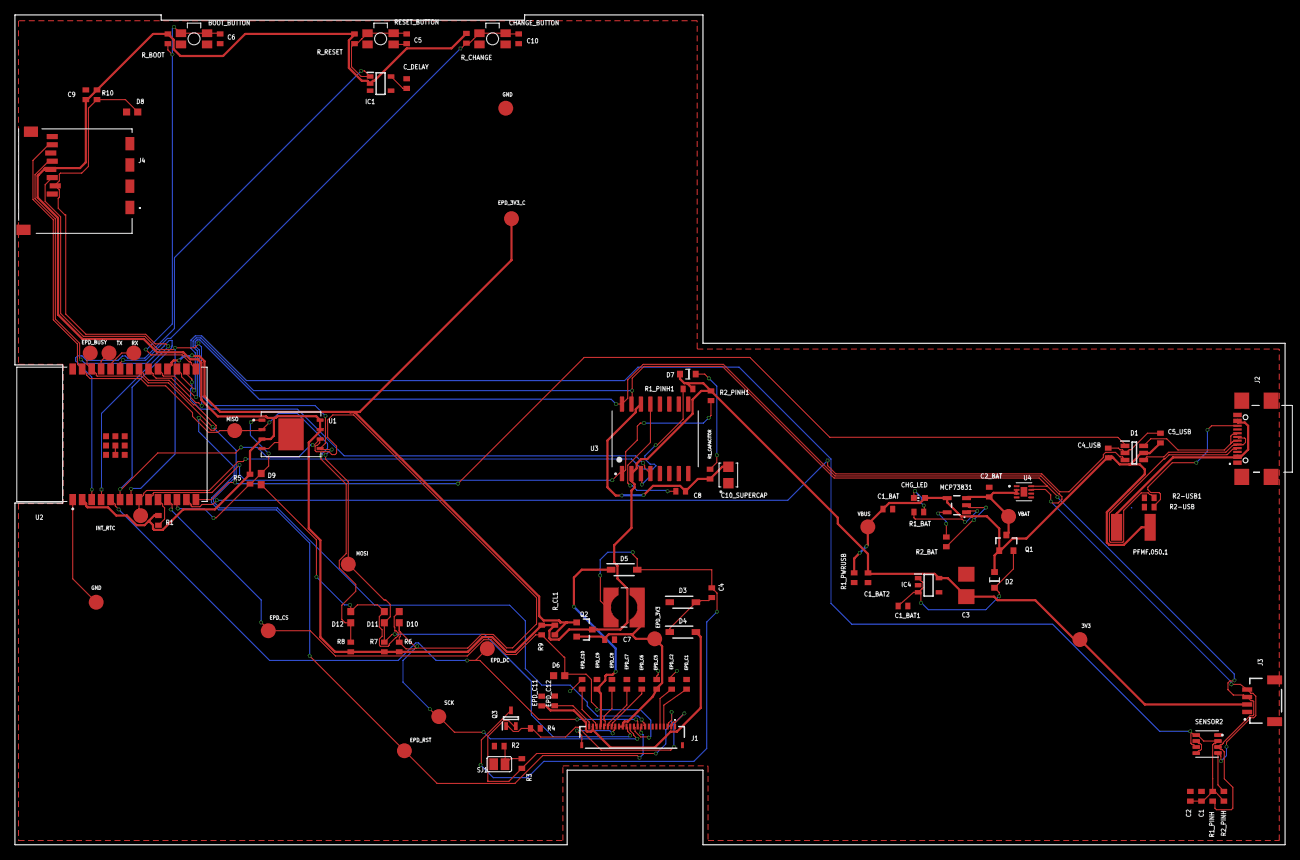
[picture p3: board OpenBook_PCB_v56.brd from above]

Board: 2 copper layers, 170.2 x 111.2 mm, 103 parts (0 on the bottom side), 55 nets.

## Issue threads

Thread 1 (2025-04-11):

[PCB] Via Stitching

Savuuu11, 2025-04-11:
Planul de masa (GND) nu acopera complet PCB-ul, existand zone neconectate pe Top.
Este necesara aplicarea unui via stitching pentru a lega planurile de masa si a asigura o acoperire completa.

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

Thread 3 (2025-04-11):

[PCB] Lipsa decupaj butoane PCB

Savuuu11, 2025-04-11:
Nu a fost realizat decupajul placutei in zona celor 3 butoane: BOOT_BUTTON, RESET_BUTTON, CHANGE_BUTTON. Acest lucru poate impiedica accesul fizic la butoane dupa asamblare.

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

Closed 2025-04-14.

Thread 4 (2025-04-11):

[PCB-3D] Componente nealiniate – distanta mare fata de carcasa

Savuuu11, 2025-04-11:
Componentele J2 (USB), J4 (SD CARD) si J3 nu sunt aliniate corespunzator conform modelului.
 Este necesara repoziționarea lor in layout-ul PCB pentru a se incadra corespunzator in modelul carcasei.

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

Closed 2025-04-14.

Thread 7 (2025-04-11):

[3D] Model 3D neconform

Savuuu11, 2025-04-11:
S a folosit un model 3D necorespunzator pentru redarea cardului SD.
Poti incerca descarcarea lui de aici:
https://store.comet.srl.ro/Catalogue/Product/43497/

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

Closed 2025-04-14.

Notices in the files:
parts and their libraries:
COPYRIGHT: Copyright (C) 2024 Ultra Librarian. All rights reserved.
